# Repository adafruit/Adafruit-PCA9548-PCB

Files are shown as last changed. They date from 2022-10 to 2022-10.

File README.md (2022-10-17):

## Adafruit PCA9548 8-Channel STEMMA QT I2C Multiplexer PCB

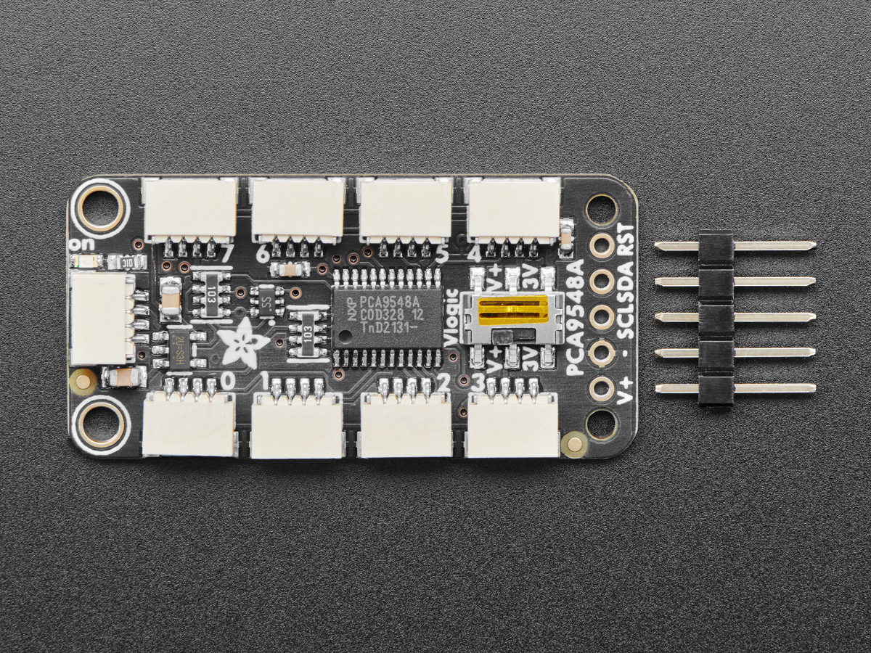
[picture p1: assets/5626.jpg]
<a href="http://www.adafruit.com/products/5626"><br/>
Click here to purchase one from the Adafruit shop</a>

PCB files for the Adafruit PCA9548 8-Channel STEMMA QT I2C Multiplexer. 

Format is EagleCAD schematic and board layout
* https://www.adafruit.com/product/5626

### Description

You just found the perfect I2C sensor, available in a handy chainable Qwiic, or STEMMA QT package, and you want to wire up two or three or more of them to your microcontroller when you realize "Uh oh, this chip has a fixed I2C address, and from what I know about I2C, you cannot have two devices with the same address on the same SDA/SCL pins!" Are you out of luck? You would be, if you didn't have this ultra-cool Adafruit PCA9548 8 Channel STEMMA QT / Qwiic I2C Multiplexer!

Finally, a way to get up to 8 same-address I2C devices hooked up to one microcontroller - this multiplexer acts as a gatekeeper, shuttling the commands to the selected I2C port with your command.

In case you're wondering why this uses the PCA9548A not the TCA9548A, the PCA9548 is the 'fraternal twin sister' of the TCA9548 but is easier to get during the great chip shortage of 2022. It works exactly the same, just can't go down to 1.8V power which is OK because QT boards are 3V or 5V only anyways. You can still use any example code or library for the TCA9548

Using it is fairly straight-forward: the multiplexer itself is on I2C address 0x70 (but can be adjusted from 0x70 to 0x77 using jumpers on the back) and you simply write a single byte with the desired multiplexed output number to that port, and bam - any future I2C packets will get sent to that port. In theory, you could have 8 of these multiplexers on each of 0x70-0x77 addresses in order to control 64 of the same-I2C-addressed-part.

The Adafruit STEMMA QT / Qwiic PCA9548A Mux Breakout - 8 Channel has eight JST SH 1mm connectors in two rows of four, all with the power, ground, and SDA/SCL pins connected. There's one port at the end that connects to your I2C controller (there are also breadboard breakout pins if you need them). Use this breakout to add as many I2C devices to the bus as you need. Complete with mounting holes so the board can be added to any system. A small power LED lets you know that the hub board has connectivity.

There's even an onboard 3.3V 500mA regulator, so if you're using this with a 5V microcontroler like an Arduino 328-compatible, you can level shift all the QT ports to have 3V power and logic level.

Of course, because STEMMA QT is Qwiic compatible, it will work with any and all STEMMA QT or Qwiic boards and parts we have in the Adafruit shop.

Comes with only the assembled PCB, no cables or sensors included (we have tons available though!)

### License

Adafruit invests time and resources providing this open source design, please support Adafruit and open-source hardware by purchasing products from [Adafruit](https://www.adafruit.com)!

Designed by Limor Fried/Ladyada for Adafruit Industries.

Creative Commons Attribution/Share-Alike, all text above must be included in any redistribution. 
See license.txt for additional details.

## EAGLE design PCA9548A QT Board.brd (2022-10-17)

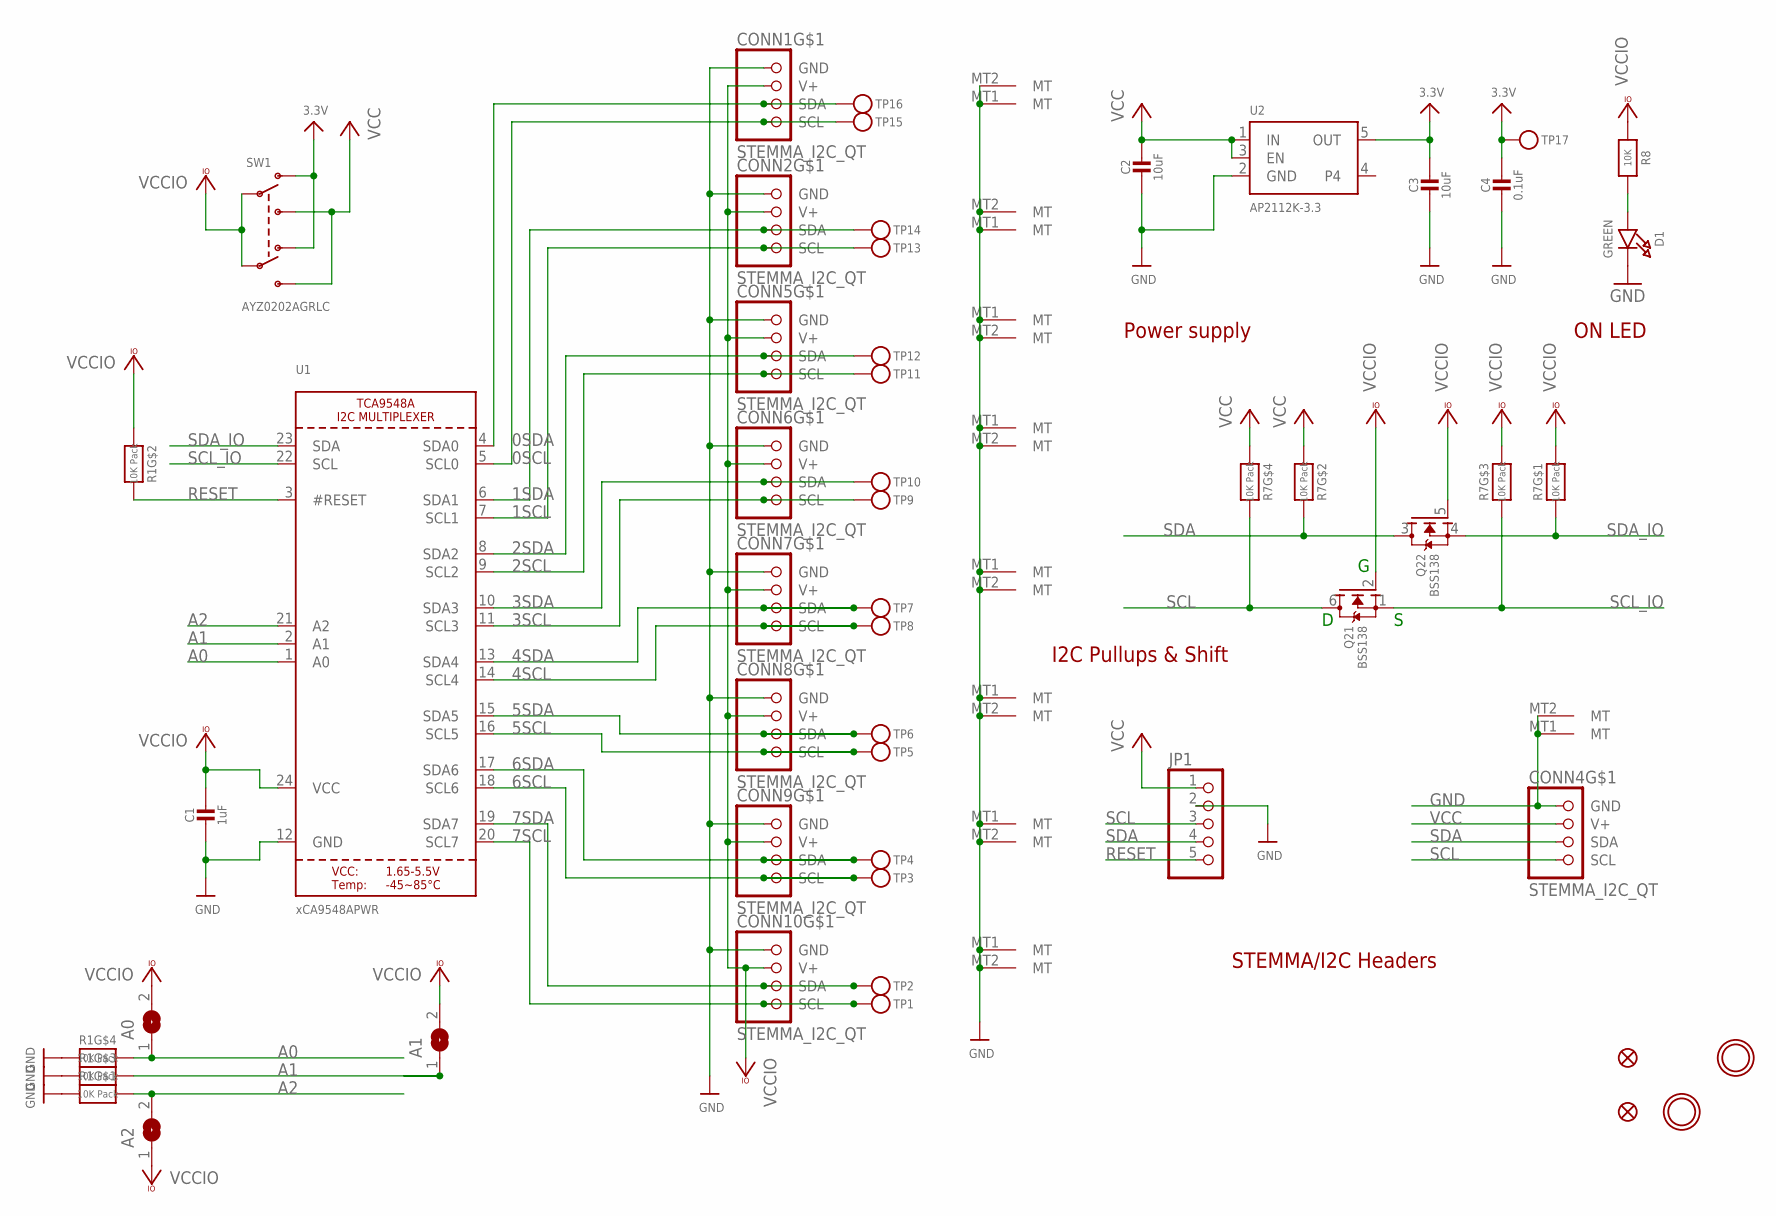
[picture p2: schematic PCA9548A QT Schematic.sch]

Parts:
A0, A1, A2: SOLDERJUMPER; SOLDERJUMPER_ARROW_NOPASTE
C1: 1uF; 0603-NO
C2, C3: 10uF; 0805-NO
C4: 0.1uF; 0603-NO
CONN1, CONN2, CONN4, CONN5, CONN6, CONN7, CONN8, CONN9, CONN10: STEMMA_I2C_QT; JST_SH4
D1: GREEN; CHIPLED_0603_NOOUTLINE
FID2, FID4: FIDUCIAL_1MM
JP1: HEADER-1X570MIL; 1X05_ROUND_70
Q2: BSS138; SOT363
R1, R7: 10K Pack; RESPACK_4X0603
R8: 10K; 0603-NO
SW1: AYZ0202AGRLC; EG1390
TP1, TP2, TP3, TP4, TP5, TP6, TP7, TP8, TP9, TP10, TP11, TP12, TP13, TP14, TP15, TP16, TP17: TESTPOINTROUND1.5MMNO; TESTPOINT_ROUND_1.5MM_NO
U1: xCA9548APWR; TSSOP24
U2: AP2112K-3.3; SOT23-5; JLC_ROTATION 0
U$19, U$22: MOUNTINGHOLE2.5; MOUNTINGHOLE_2.5_PLATED

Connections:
0SCL: CONN1.4 (SCL), TP15.P$1, U1.5 (SCL0)
0SDA: CONN1.3 (SDA), TP16.P$1, U1.4 (SDA0)
1SCL: CONN2.4 (SCL), TP13.P$1, U1.7 (SCL1)
1SDA: CONN2.3 (SDA), TP14.P$1, U1.6 (SDA1)
2SCL: CONN5.4 (SCL), TP11.P$1, U1.9 (SCL2)
2SDA: CONN5.3 (SDA), TP12.P$1, U1.8 (SDA2)
3.3V: C3.1, C4.1, SW1.O1, SW1.O2, TP17.P$1, U2.5 (OUT)
3SCL: CONN6.4 (SCL), TP9.P$1, U1.11 (SCL3)
3SDA: CONN6.3 (SDA), TP10.P$1, U1.10 (SDA3)
4SCL: CONN7.4 (SCL), TP8.P$1, U1.14 (SCL4)
4SDA: CONN7.3 (SDA), TP7.P$1, U1.13 (SDA4)
5SCL: CONN8.4 (SCL), TP5.P$1, U1.16 (SCL5)
5SDA: CONN8.3 (SDA), TP6.P$1, U1.15 (SDA5)
6SCL: CONN9.4 (SCL), TP3.P$1, U1.18 (SCL6)
6SDA: CONN9.3 (SDA), TP4.P$1, U1.17 (SDA6)
7SCL: CONN10.4 (SCL), TP1.P$1, U1.20 (SCL7)
7SDA: CONN10.3 (SDA), TP2.P$1, U1.19 (SDA7)
A0: A0.1, R1.5 (2), U1.1 (A0)
A1: A1.1, R1.6 (2), U1.2 (A1)
A2: A2.2, R1.8 (2), U1.21 (A2)
GND: C1.2, C2.2, C3.2, C4.2, CONN1.1 (GND), CONN1.MT1 (MT), CONN1.MT2 (MT), CONN2.1 (GND), CONN2.MT1 (MT), CONN2.MT2 (MT), CONN4.1 (GND), CONN4.MT1 (MT), CONN4.MT2 (MT), CONN5.1 (GND), CONN5.MT1 (MT), CONN5.MT2 (MT), CONN6.1 (GND), CONN6.MT1 (MT), CONN6.MT2 (MT), CONN7.1 (GND), CONN7.MT1 (MT), CONN7.MT2 (MT), CONN8.1 (GND), CONN8.MT1 (MT), CONN8.MT2 (MT), CONN9.1 (GND), CONN9.MT1 (MT), CONN9.MT2 (MT), CONN10.1 (GND), CONN10.MT1 (MT), CONN10.MT2 (MT), D1.C, JP1.2, R1.1, R1.3 (1), R1.4 (1), U1.12 (GND), U2.2 (GND)
unnamed: D1.A, R8.2
RESET: JP1.5, R1.7 (2), U1.3 (#RESET)
SCL: CONN4.4 (SCL), JP1.3, Q2.6 (D), R7.5 (2)
SCL_IO: Q2.1 (S), R7.6 (2), U1.22 (SCL)
SDA: CONN4.3 (SDA), JP1.4, Q2.3 (D), R7.7 (2)
SDA_IO: Q2.4 (S), R7.8 (2), U1.23 (SDA)
VCC: C2.1, CONN4.2 (V+), JP1.1, R7.2 (1), R7.4 (1), SW1.S1, SW1.S2, U2.1 (IN), U2.3 (EN)
VCCIO: A0.2, A1.2, A2.1, C1.1, CONN1.2 (V+), CONN2.2 (V+), CONN5.2 (V+), CONN6.2 (V+), CONN7.2 (V+), CONN8.2 (V+), CONN9.2 (V+), CONN10.2 (V+), Q2.2 (G), Q2.5 (G), R1.2 (1), R7.1, R7.3 (1), R8.1, SW1.P1, SW1.P2, U1.24 (VCC)

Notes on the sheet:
I2C Pullups & Shift
STEMMA/I2C Headers
ON LED
Power supply

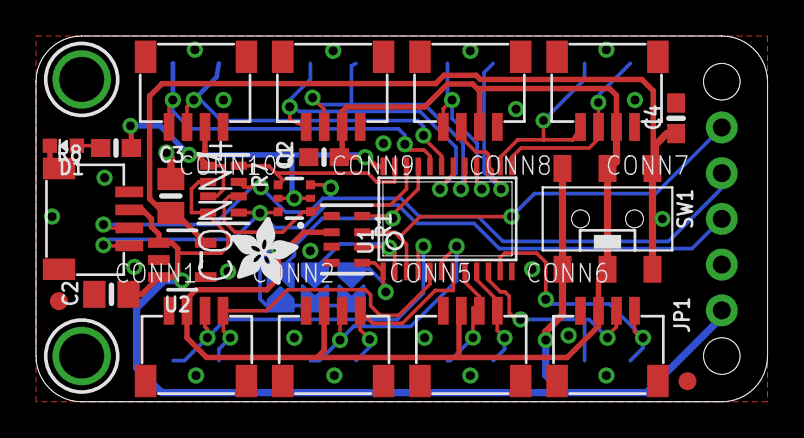
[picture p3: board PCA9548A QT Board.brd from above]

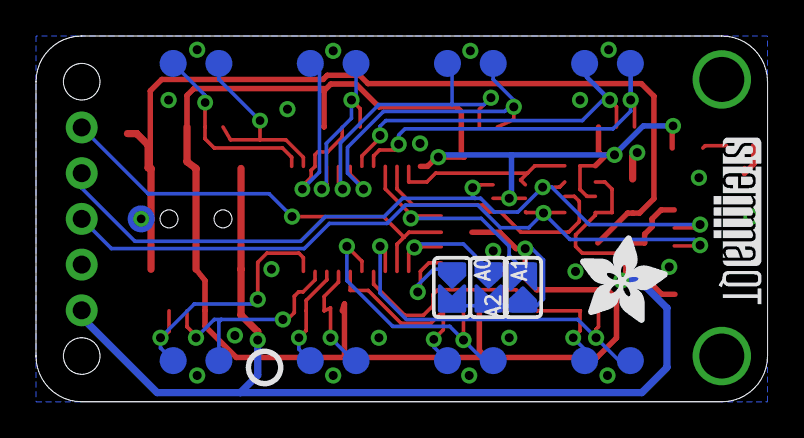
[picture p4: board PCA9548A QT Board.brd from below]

Board: 2 copper layers, 40.6 x 20.3 mm, 75 parts (28 on the bottom side), 29 nets.

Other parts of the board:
PLABEL0: PLABEL0
PLABEL1: PLABEL1
PLABEL2: PLABEL2
PLABEL3: PLABEL3
PLABEL4: PLABEL4
PLABEL5: PLABEL5
PLABEL6: PLABEL6
PLABEL7: PLABEL7
PLABEL8: PLABEL8
PLABEL9: PLABEL9
PLABEL10: PLABEL10
PLABEL11: PLABEL11
PLABEL12: PLABEL12
PLABEL13: PLABEL13
PLABEL14: PLABEL14
PLABEL15: PLABEL15
PLABEL16: PLABEL16
PLABEL17: PLABEL17
PLABEL18: PLABEL18
PLABEL19: PLABEL19
PLABEL20: PLABEL20
PLABEL21: PLABEL21
PLABEL22: PLABEL22
PLABEL23: PLABEL23
PLABEL24: PLABEL24
U$5: ADAFRUIT_5MM
U$28: ADAFRUIT_3.5MM
U$29: PCBFEAT-REV-040
U$31: STEMMAQT

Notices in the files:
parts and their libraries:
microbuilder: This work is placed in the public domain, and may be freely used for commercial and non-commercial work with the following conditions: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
